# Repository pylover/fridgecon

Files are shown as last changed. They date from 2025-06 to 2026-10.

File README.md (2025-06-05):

# fridgecon
Simple refrigerator controller.

## Schematic
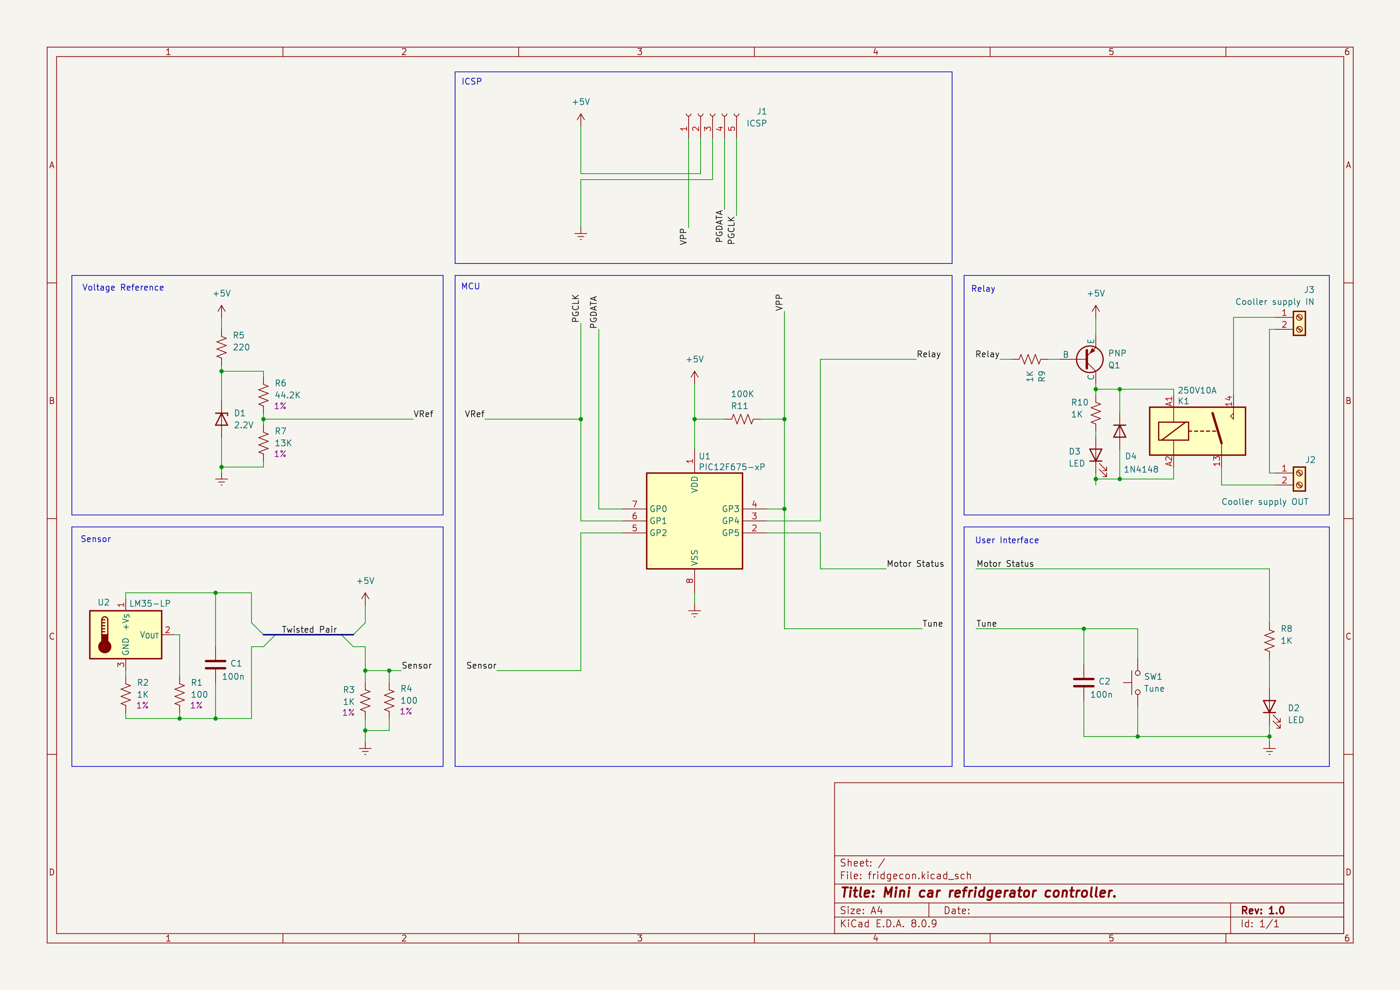
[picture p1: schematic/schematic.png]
fridgecon-circuit


## Build

### Prepare

Download and install `XC8` compiler from [Microchip's
website](https://www.microchip.com/en-us/tools-resources/develop/mplab-xc-compilers/xc8#downloads).

Clone and install `ardpicprog` from [my
fork](https://github.com/pylover/ardpicprog?tab=readme-ov-file).

then
```bash
make
```

### Program the chip
```bash
make program
```

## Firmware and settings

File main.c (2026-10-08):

/* configuration bits must be define before any include */
#include "configbits.h"
#include "userconfig.h"
#include <xc.h>
#include "store.h"
#include "timer.h"


static __bit _blinking;
static __bit _tunning;
static volatile signed char temp;
static signed char _offtemp = OFFTEMP_DEFAULT;
#define _RELAY GP4
#define _LED GP5
#define _TBTN GP3
#define MOTOR_SET(s) _RELAY = !(s)
#define LED_SET(s) _LED = (s)
#define LED_TOGGLE(s) _LED ^= 1
#define BLINKWAIT(n, i) \
    _blinking = true; \
    timer_async((n), TICKS(i), _blink); \
    while (_blinking) _delaywdt(MILI(50))


static void
_init() {
    /* Callibrate the 4MHZ internal oscilator */
    OSCCAL = 0b01001000;

    /* comprator off */
    CMCON = 0b00000111;
    VRCON = 0b00000000;

    /* option reg
     * 7. enable global pull up control active low: GPPU
     * 6. interrupt on falling edge of GP2, default.
     * 5. tmr0 uses internal clock
     * 4. Increment on low-to-high transition on GP2/T0CKI pin
     * 3. prescaler is assigned to wdt module
     * 2:0. prescale 1/128 for wdt.
     */
    OPTION_REG = 0b00001111;

    /* GP2, 1 and 3 as input */
    TRISIO = 0b00001110;

    /* GP3 weak pullup */
    WPU = 0b00001000;

    /* interrrupt on change GP3 */
    IOC = 0b00001000;

    /* adc configuration
     *   7. right justified result format
     *   6. vref pin enabled
     * 3:2. analog channel selection: ch 10
     *   0. ADON enable ADC module
     */
    ADCON0 = 0b11001001;

    /* enable analog input for GP2/AN2
     * ADC clock drived from internal clock < 500KH */
    ANSEL = 0b00110100;

    /* interrupt control
     * 7. GIE: Enables all unmasked interrupts
     * 6. enable all unmasked peripheral interrupts
     * 5. disable the TMR0 interrupt
     * 4. disable the GP2/INT external interrupt
     * 3. enable the GPIO port change interrupt
     * 2. TMR0 register did not overflow
     * 1. clear INTF
     * 0. GPIF None of the GP5:GP0 pins have changed state
     */
    INTCON = 0b11001000;

    // _offtemp = offtemp_load();
    timer_init();

    ADIE = 1;
}


void __interrupt()
isr(void) {
    unsigned short adcval;

    if (GPIF) {
        GPIF = 0;
        if (_tunning) {
            return;
        }
        TMR1ON = 0;
        _blinking = false;
        _tunning = true;
    }

    if (ADIF) {
        adcval = (unsigned short)ADRESH << 8;
        adcval += (unsigned short)ADRESL;
        temp = (signed char) (adcval / ADC_FACTOR);
        temp += TEMP_OFFSET_CELSIUS;
        ADIF = 0;
    }

    if (TMR1IF) {
        timer_tick();
        TMR1IF = 0;
    }
}


static void
_blink(unsigned int countdown) {
    LED_TOGGLE();
    if (countdown == 0) {
        _blinking = false;
    }
}


static void
_tune(unsigned int countdown) {
    LED_TOGGLE();
    if (countdown == 0) {
        _tunning = false;
    }
}


static int
_sample(void) {
    while (!_tunning) {
        GO_nDONE = 1;   // ADC enable
        while (GO_nDONE == 1){
            _delaywdt(100);
        }
        LED_TOGGLE();
        if (temp < _offtemp) {
            return 1;
        }
        else if (temp > ONTEMP) {
            MOTOR_SET(ON);
        }
        _delaywdt(MILI(1000));
    }
    return 0;
}


void
main(void) {
    _init();

normal:
    /* turn compressor off */
    MOTOR_SET(OFF);
    LED_SET(OFF);
    _delaywdt(SECOND(2));
    BLINKWAIT(MOTORON_DELAY_S * 10, MILI(100));

    MOTOR_SET(ON);
    _delaywdt(SECOND(2));
    BLINKWAIT(MOTORON_S * 5, MILI(200));
    goto normal;

    // /* tunning */
    // _offtemp--;
    // if (_offtemp < OFFTEMP_MIN) {
    //     _offtemp = OFFTEMP_MAX;
    // }
    // offtemp_save(_offtemp);
    // LED_SET(OFF);
    // BLINKWAIT(4, MILI(50));
    // _delaywdt(MILI(700));
    // timer_async((unsigned int)abs(_offtemp) * 2, TICKS(MILI(300)), _tune);
    // while (_tunning) {
    //     _delaywdt(MILI(100));
    // }
    goto normal;
}

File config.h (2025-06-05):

#ifndef CONFIG_H_
#define CONFIG_H_

// PIC12F675 Configuration Bit Settings

// 'C' source line config statements

// BEGIN CONFIG
// 100 = INTOSC oscillator: I/O function on GP4/OSC2/CLKOUT pin, I/O function on GP5/OSC1/CLKIN
// #pragma config FOSC = INTRCIO
//
/*
111 = RC oscillator: CLKOUT function on GP4/OSC2/CLKOUT pin, RC on GP5/OSC1/CLKIN
110 = RC oscillator: I/O function on GP4/OSC2/CLKOUT pin, RC on GP5/OSC1/CLKIN
101 = INTOSC oscillator: CLKOUT function on GP4/OSC2/CLKOUT pin, I/O function on GP5/OSC1/CLKIN
100 = INTOSC oscillator: I/O function on GP4/OSC2/CLKOUT pin, I/O function on GP5/OSC1/CLKIN
011 = EC: I/O function on GP4/OSC2/CLKOUT pin, CLKIN on GP5/OSC1/CLKIN
010 = HS oscillator: High speed crystal/resonator on GP4/OSC2/CLKOUT and GP5/OSC1/CLKIN
001 = XT oscillator: Crystal/resonator on GP4/OSC2/CLKOUT and GP5/OSC1/CLKIN
000 = LP oscillator: Low-power crystal on GP4/OSC2/CLKOUT and GP5/OSC1/CLKIN
*/
#pragma config FOSC = 4

// Watchdog Timer Enable bit (WDT enabled)
#pragma config WDTE = ON

// Power-Up Timer Enable bit (PWRT disabled)
#pragma config PWRTE = ON

// GP3/MCLR pin function select (GP3/MCLR pin function is R)
#pragma config MCLRE = OFF

// Brown-out Detect Enable bit (BOD enabled)
#pragma config BOREN = OFF

// Code Protection bit (Program Memory code protection is disabled)
#pragma config CP = OFF

// Data Code Protection bit (Data memory code protection is disabled)
#pragma config CPD = OFF
// END CONFIG

// #pragma config statements should precede project file includes.
// Use project enums instead of #define for ON and OFF.


#include <xc.h>
#include <stdbool.h>

#include "helpers.h"


#define VREF_MV 476
#define ADC_MAX 1024

/* ADC_MAX / VREF_MV */
#define ADC_FACTOR 22
#define ADC_OFFSET_CELSIUS -5


#define OFFTEMP_MIN -5
#define OFFTEMP_MAX -1
#define OFFTEMP_DEFAULT -1
#define ONTEMP 4
// #define MOTORON_DELAY_S (60 * 3)
// #define MOTORON_DELAY_S 2
#define MOTORON_DELAY_S 30


#endif  // CONFIG_H_

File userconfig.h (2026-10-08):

#ifndef USERCONFIG_H_
#define USERCONFIG_H_


#include <stdbool.h>
#include "helpers.h"


/* ADC volatge refrence defined by D1 and pair of (R6, R7) voltage devider. */
#define VREF_MV 476


/* PIC12F675 ADC resolution is 10 bits. so 2 ^ 10 */
#define ADC_MAX 1024


/* ADC_MAX / VREF_MV */
#define ADC_FACTOR 22


/* temperature offset */
#define TEMP_OFFSET_CELSIUS -5


/* minimum/maximum allowed temperature to turn off the fridge compressor */
#define OFFTEMP_MIN -5
#define OFFTEMP_MAX -1
#define OFFTEMP_DEFAULT -1


/* temperature to turn the fridge compressor on */
#define ONTEMP 1


/* delay before turn the compressor on after power outage and etc. */
#define MOTORON_DELAY_S (6 * 60)
#define MOTORON_S (20 * 60)


/* delay before turn the compressor off after the OFFTEMP has reached. */
#define MOTOROFF_DELAY_S (10 * 60)


#endif  // USERCONFIG_H_

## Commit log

2025-05-15 Initial schematic and firmware
    [fridgecon.kicad_pcb, fridgecon.kicad_sch]
2025-05-17 lm35 output rerouted to GP0/AN0 and GP2 used for push button interrupt
2025-05-18 feature: GP2/INT
    [fridgecon.kicad_sch]
2025-05-18 Feature: push button moved on GP3
2025-05-18 Feature: lm35 sensor moved to GP2
2025-05-18 Feature: tune feedback LED
2025-05-20 Feature: watchdog time
    [fridgecon.kicad_sch]
2025-05-21 Feature: timer and callback
2025-05-21 Feature: persistant temperature limits
2025-05-21 Feature: Temperature tunning loop
2025-05-21 Fix: tune during boot
    [main.c]
2025-06-05 Feature: schematic
    [fridgecon.kicad_sch]
2025-06-05 Feature: wait MOTOROFF_DELAY_S seconds before turn the compressor off
2025-06-05 Fix: unused macro function parameter
    [main.c]
2025-06-05 Feature: schematic inside the readme
2025-06-11 Final patches
    [fridgecon.kicad_sch]
